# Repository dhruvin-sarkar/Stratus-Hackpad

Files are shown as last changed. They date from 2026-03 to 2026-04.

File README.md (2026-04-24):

# Stratus Hackpad

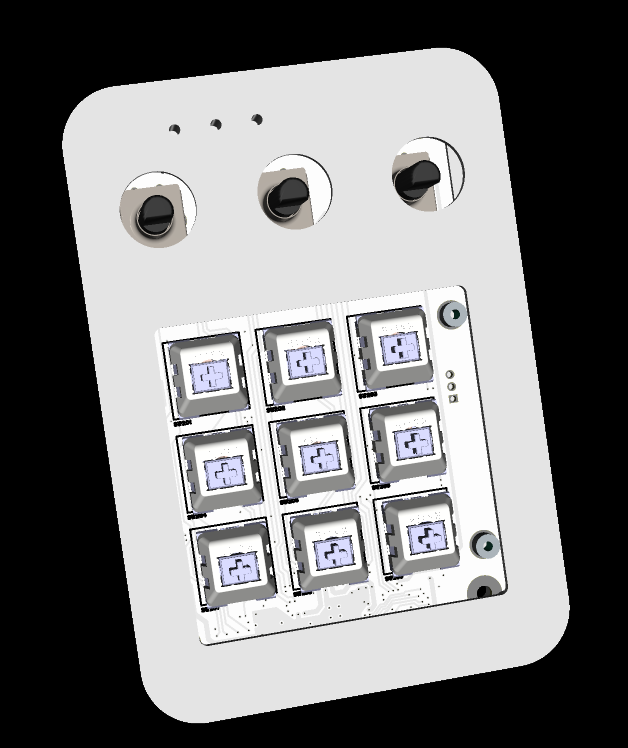
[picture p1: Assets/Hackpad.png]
Stratus Hackpad


---

## Overview

The **Stratus Hackpad** is a DIY macropad. It features nine hot-swap mechanical key switches in a 3×3 layout, three rotary encoders with push-click switches, per-key addressable RGB LEDs viewable through transparent light guides, and a USB-C connection  all controlled by the Raspberry Pi RP2040 microcontroller.

---

## Tutorial Playlist

A full step-by-step video tutorial series covering everything from sourcing parts to flashing firmware is coming soon. Follow along to build your own Stratus Hackpad from scratch!

> **[Tutorial Playlist — Coming Soon]**

The playlist will cover PCB ordering, soldering the SMD components, assembling the case, flashing QMK/KMK firmware, and customising your layout.

---

## Photos

| Assembled | Inside | PCB |
|---|---|---|
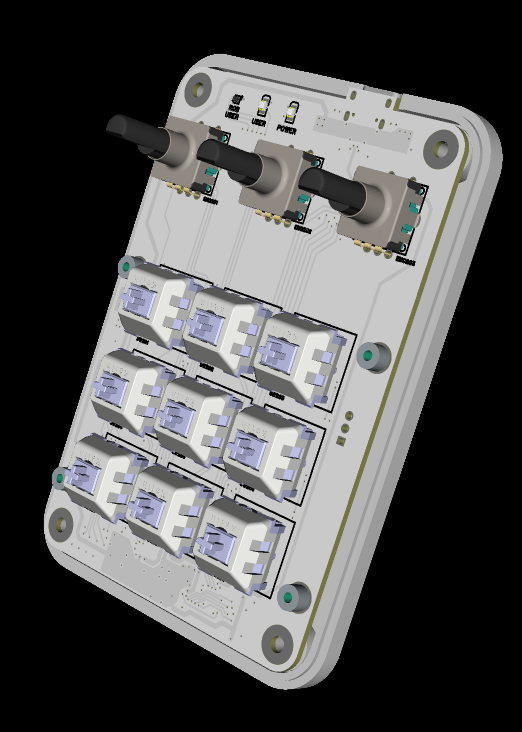
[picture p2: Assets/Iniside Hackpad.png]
Inside
| Hackpad |  | PCB |

| Case Showcase | Schematic — MCU Page | Schematic — Other |
|---|---|---|
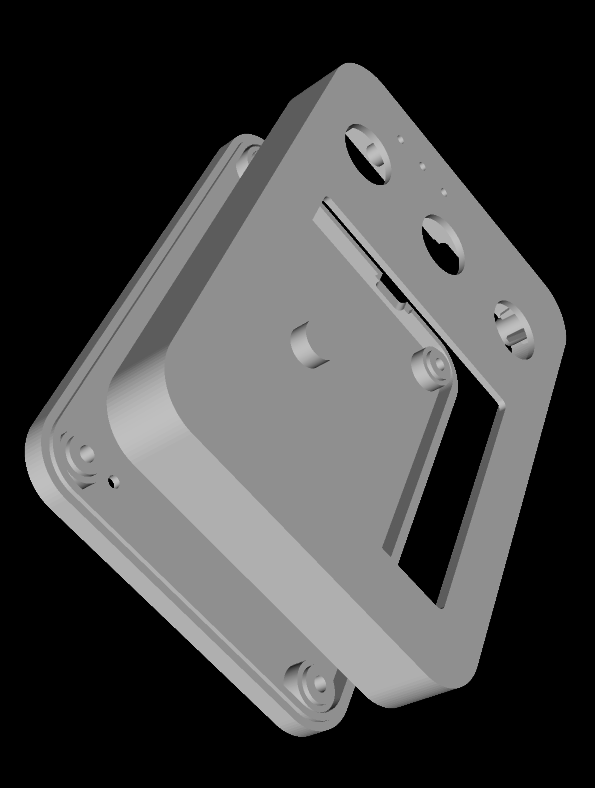
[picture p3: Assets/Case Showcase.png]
Case
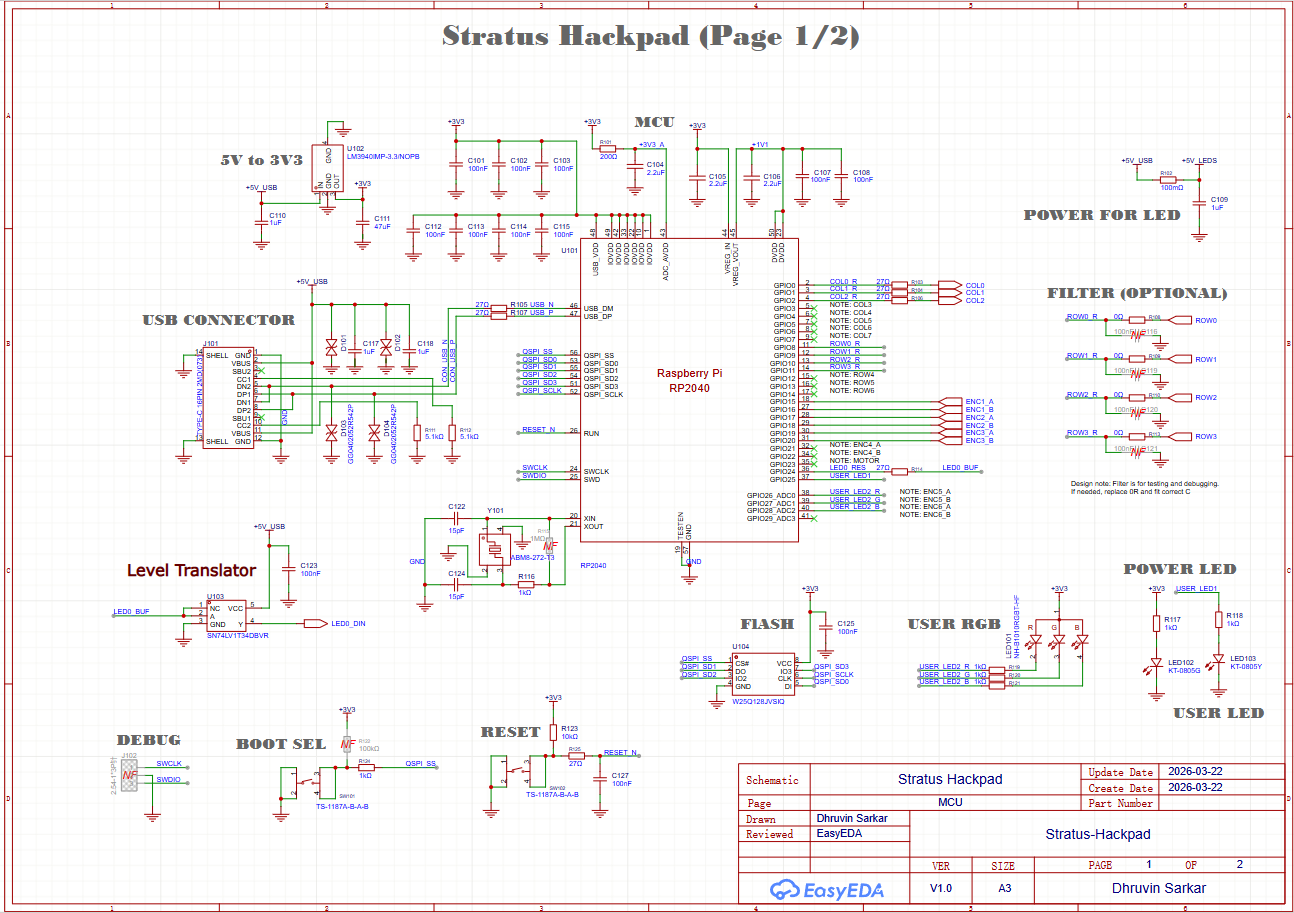
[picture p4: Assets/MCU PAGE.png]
MCU Page
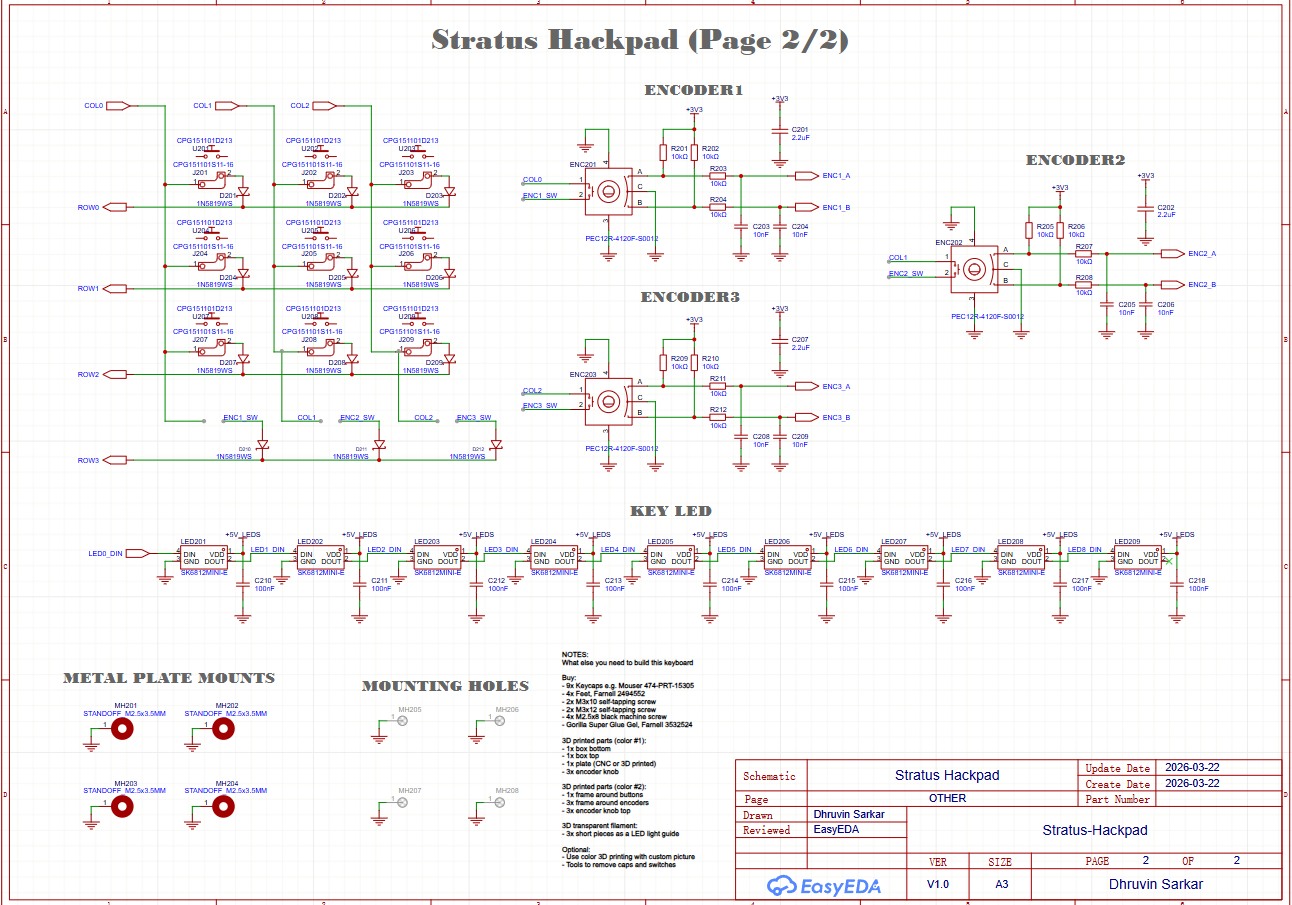
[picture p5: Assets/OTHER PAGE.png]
Other Page
|  |  |  |

---

## Bill of Materials (PCB)

All PCB components are sourced primarily from **LCSC**, with standoffs from **Farnell**.

| # | Qty | Component | Designator | Part Number | Supplier |
|---|-----|---|---|---|---|
| 1 | 7 | Cap 2.2µF 0402 | C101, C105–C107, C201, C202, C207 | CL05A225MQ5NSNC | LCSC C12530 |
| 2 | 21 | Cap 100nF 0402 | C102–C104, C108–C109, C113–C116, C125–C127, C210–C218 | CL05B104KO5NNNC | LCSC C1525 |
| 3 | 4 | Cap 1µF 0402 | C110, C111, C118, C119 | CL05A105KA5NQNC | LCSC C52923 |
| 4 | 1 | Cap 47µF 1206 | C112 | CL31A476MPHNNNE | LCSC C96123 |
| 5 | 2 | Cap 15pF 0402 | C123, C124 | CL05C150JB5NNNC | LCSC C86285 |
| 6 | 6 | Cap 10nF 0402 | C203–C206, C208, C209 | CL05B103KB5NNNC | LCSC C15195 |
| 7 | 4 | TVS Diode (bi-dir) | D101–D104 | GG0402052R542P | LCSC C1973257 |
| 8 | 12 | Schottky Diode 1N5819WS | D201–D212 | 1N5819WS | LCSC C191023 |
| 9 | 3 | Rotary Encoder PEC12R | ENC201–ENC203 | PEC12R-4120F-S0012 | LCSC C143801 |
| 10 | 1 | USB-C Connector 16-pin | J101 | TYPE-C 16PIN 2MD(073) | LCSC C2765186 |
| 11 | 9 | Kailh Hot-swap Socket | J201–J209 | CPG151101S11-16 | LCSC C5156480 |
| 12 | 1 | RGB LED Array (status) | LED101 | NH-B1010RGBT-HF | LCSC C2874113 |
| 13 | 1 | LED Green 0805 | LED102 | KT-0805G | LCSC C2297 |
| 14 | 1 | LED Yellow 0805 | LED103 | KT-0805Y | LCSC C2296 |
| 15 | 9 | SK6812MINI-E RGB LED | LED201–LED209 | SK6812MINI-E | LCSC C5149201 |
| 16 | 4 | Standoff M2.5×3.5mm | MH201–MH204 | 3757968 | Farnell |
| 17 | 1 | Resistor 200Ω 0402 | R101 | 0402WGF2000TCE | LCSC C25087 |
| 18 | 1 | Resistor 100mΩ 1206 | R102 | 1206W4F100LT5E | LCSC C25334 |
| 19 | 7 | Resistor 1kΩ 0402 | R103–R107, R121, R124 | 0402WGF1001TCE | LCSC C11702 |
| 20 | 7 | Resistor 27Ω 0402 | R108–R112, R117, R125 | 0402WGF270JTCE | LCSC C25100 |
| 21 | 4 | Resistor 0Ω 0402 | R113–R116 | 0402WGF0000TCE | LCSC C17168 |
| 22 | 2 | Resistor 5.1kΩ 0402 | R118, R119 | 0402WGF5101TCE | LCSC C25905 |
| 23 | 13 | Resistor 10kΩ 0402 | R123, R201–R212 | 0402WGF1002TCE | LCSC C25744 |
| 24 | 2 | Tactile Switch 5.1mm | SW101, SW102 | TS-1187A-B-A-B | LCSC C318884 |
| 25 | 9 | Kailh Switch CPG151101S21 | SW201–SW209 | CPG151101S21 | LCSC C404351 |
| 26 | 1 | RP2040 MCU | U101 | RP2040 | LCSC C2040 |
| 27 | 1 | LDO Regulator 3.3V | U102 | LM3940IMP-3.3/NOPB | LCSC C140319 |
| 28 | 1 | Buffer SN74LV1T34 | U103 | SN74LV1T34DBVR | LCSC C100024 |
| 29 | 1 | Flash 128Mbit SPI | U104 | W25Q128JVSIQ | LCSC C97521 |
| 30 | 1 | Crystal 12MHz | Y101 | ABM8-272-T3 | LCSC C20625731 |

---

### Hardware to Buy

- **9× Keycaps** — e.g. Mouser `474-PRT-15305`
- **4× Rubber feet** — Farnell `2494552`
- **2× M3×10 self-tapping screws**
- **2× M3×12 self-tapping screws**
- **4× M2.5×8 black machine screws**
- **Gorilla Super Glue Gel** — Farnell `3532524`

### 3D Printed Parts — Colour #1 (main body colour)

- 1× Box bottom
- 1× Box top
- 1× Switch plate (can also be CNC machined)
- 3× Encoder knob (body)

### 3D Printed Parts — Colour #2 (accent colour)

- 1× Frame around buttons
- 3× Frame around encoders
- 3× Encoder knob top

### 3D Printed — Transparent Filament

- 3× Short pieces used as LED light guides (one per encoder/LED position)
---

## Firmware

The Stratus Hackpad is compatible with both **QMK** and **KMK** (CircuitPython-based). Starter configuration files are provided.

---

## Contributing

Pull requests and issues are welcome! If you build one, share a photo it's always great to see the community's builds.

# Set shortcuts
To set shortcuts on your keyboard, use VIA.
1. When connecting your keyboard for very first time, go to https://usevia.app/design click LOAD and use keyboard_layout_for _VIA.json to see your keyboard in VIA
1. To change shortcuts, go to https://usevia.app/ and in the right top corner click on "Authorize New +"
1. Pair your Stratus Hackpad
1. Set shortcuts

# Steps to update firmware
1. Connect your keyboard to PC
1. Double tap the reset button on your keyboard
1. Keyboard will show up as an USB storage
1. Copy and paste uf2 firmware file from your PC directly to the USB storage main directory

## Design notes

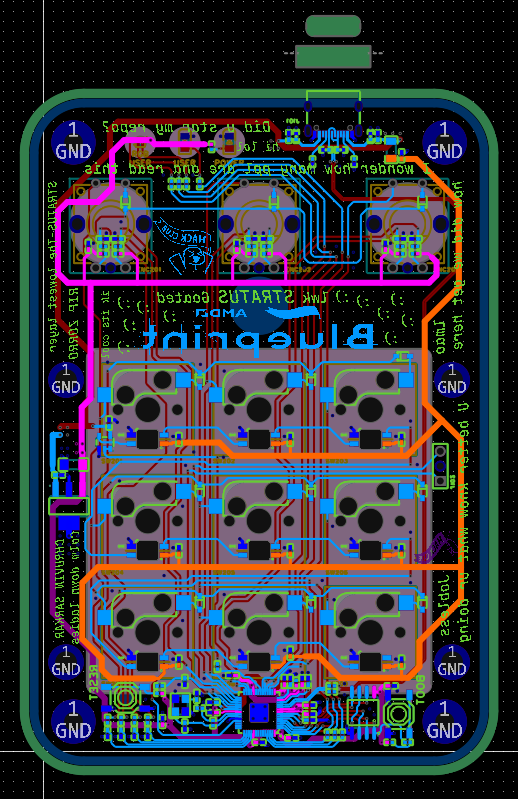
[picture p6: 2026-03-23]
Assets/PCB Vert.png

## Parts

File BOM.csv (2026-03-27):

Name | Purpose | Quantity | Total Cost | Link | Distributor
100nF Capacitor (CL05B104KO5NNNC) | Decoupling capacitor for MCU and LED power pins | 21 | $1.05 | https://www.lcsc.com/product-detail/C1525.html | LCSC
2.2uF Capacitor (CL05A225MQ5NSNC) | Bulk decoupling and power filtering | 6 | $0.6 | https://www.lcsc.com/product-detail/C12530.html | LCSC
1uF Capacitor (CL05A105KA5NQNC) | Power filtering for regulator and USB | 4 | $0.6 | https://www.lcsc.com/product-detail/C52923.html | LCSC
47uF Capacitor (CL31A476MPHNNNE) | Bulk output capacitor for LDO regulator | 1 | $0.25 | https://www.lcsc.com/product-detail/C96123.html | LCSC
15pF Capacitor (CL05C150JB5NNNC) | Crystal oscillator load capacitors | 2 | $0.2 | https://www.lcsc.com/product-detail/C86285.html | LCSC
10nF Capacitor (CL05B103KB5NNNC) | Low pass filter capacitors for encoder signals | 6 | $0.3 | https://www.lcsc.com/product-detail/C15195.html | LCSC
ESD Protection Diode (GG0402052R542P) | USB-C ESD protection | 4 | $9.36 | https://www.lcsc.com/product-detail/C1973257.html | LCSC
Schottky Diode 1N5819WS | Keyboard matrix anti-ghosting diodes | 12 | $3.48 | https://www.lcsc.com/product-detail/C191023.html | LCSC
Rotary Encoder PEC12R-4120F-S0012 | Rotary encoders with push switch | 3 | $9.3 | https://www.lcsc.com/product-detail/C143801.html | LCSC
USB-C Connector TYPE-C 16PIN 2MD(073) | USB-C connector for power and data | 1 | $0.67 | https://www.lcsc.com/product-detail/C2765186.html | LCSC
Kailh Hotswap Socket CPG151101S11-16 | Hotswap sockets for mechanical switches | 9 | $5.94 | https://www.lcsc.com/product-detail/C5156480.html | LCSC
RGB LED NH-B1010RGBT-HF | User RGB status indicator LED | 1 | $0.5 | https://www.lcsc.com/product-detail/C2874113.html | LCSC
Green LED KT-0805G | User programmable indicator LED | 1 | $0.8 | https://www.lcsc.com/product-detail/C2297.html | LCSC
Yellow LED KT-0805Y | Power indicator LED | 1 | $0.33 | https://www.lcsc.com/product-detail/C2296.html | LCSC
SK6812MINI-E RGB LED | Per-key RGB LEDs for keyboard backlight | 9 | $4.5 | https://www.lcsc.com/product-detail/C5149201.html | LCSC
M2.5x3.5mm Standoff | Metal plate standoffs for switch plate support | 4 |  | https://www.farnell.com/search/?st=9774035151 | FARNELL
200Ω Resistor (0402WGF2000TCE) | Current limiting resistor for power LED | 1 | $0.05 | https://www.lcsc.com/product-detail/C25087.html | LCSC
100mΩ Resistor (1206W4F100LT5E) | Current sense resistor for LED power | 1 | $0.04 | https://www.lcsc.com/product-detail/C25334.html | LCSC
27Ω Resistor (0402WGF270JTCE) | USB data line and signal series termination resistors | 7 | $0.35 | https://www.lcsc.com/product-detail/C25100.html | LCSC
0Ω Resistor (0402WGF0000TCE) | DNF filter jumpers | 4 | $0.2 | https://www.lcsc.com/product-detail/C17168.html | LCSC
5.1kΩ Resistor (0402WGF5101TCE) | USB-C CC pull down resistors | 2 | $0.1 | https://www.lcsc.com/product-detail/C25905.html | LCSC
1kΩ Resistor (0402WGF1001TCE) | LED current limiting and signal resistors | 7 | $0.35 | https://www.lcsc.com/product-detail/C11702.html | LCSC
10kΩ Resistor (0402WGF1002TCE) | Pull-up resistors for encoders and reset | 13 | $0.65 | https://www.lcsc.com/product-detail/C25744.html | LCSC
Tactile Switch TS-1187A-B-A-B | Boot and reset buttons | 2 | $1.1 | https://www.lcsc.com/product-detail/C318884.html | LCSC
RP2040 Microcontroller | Main MCU for keyboard firmware | 1 | $3.46 | https://www.lcsc.com/product-detail/C2040.html | LCSC
LM3940IMP-3.3 LDO Regulator | 5V to 3.3V voltage regulator | 1 | $1.55 | https://www.lcsc.com/product-detail/C140319.html | LCSC
SN74LV1T34DBVR Level Translator | 3.3V to 5V logic level buffer for RGB LEDs | 1 | $0.51 | https://www.lcsc.com/product-detail/C100024.html | LCSC
W25Q128JVSIQ Flash Memory | 16MB external flash for firmware storage | 1 | $0.34 | https://www.lcsc.com/product-detail/C97521.html | LCSC
Kailh Key Socket CPG151101D213 | Through-hole hotswap sockets | 9 | $13.32 | https://www.lcsc.com/product-detail/C400235.html | LCSC
12MHz Crystal ABM8-272-T3 | Crystal oscillator for RP2040 USB clock | 1 | $1.84 | https://www.lcsc.com/product-detail/C20625731.html | LCSC

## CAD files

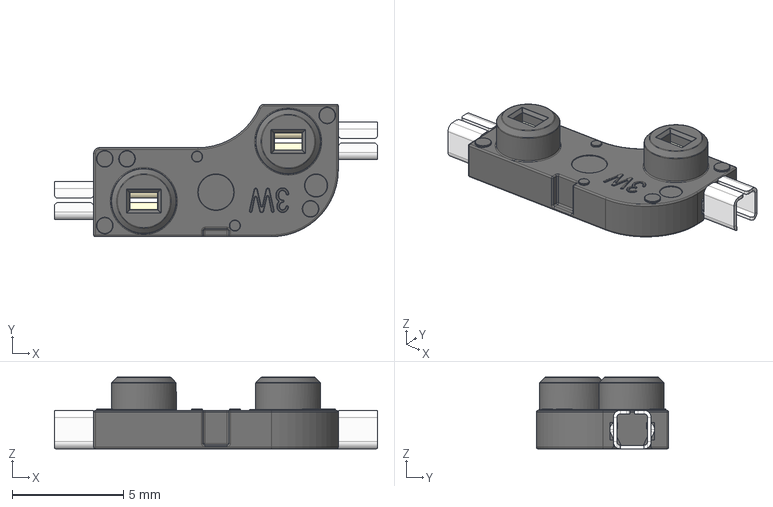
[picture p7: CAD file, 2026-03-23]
3D models/Kailh Hotswap MX v22 DS v1_0.step
14.5 x 5.95 x 3.22 mm

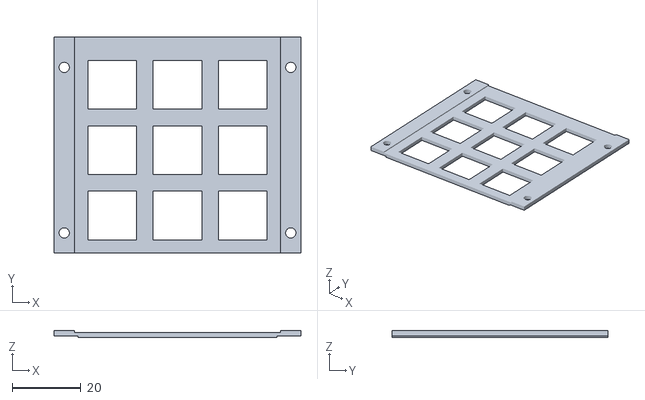
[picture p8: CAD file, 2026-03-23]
Manufacturing/Knobs and Plates/plate_for_industrial_printing_2mm.stl
72.0 x 63.0 x 2.00

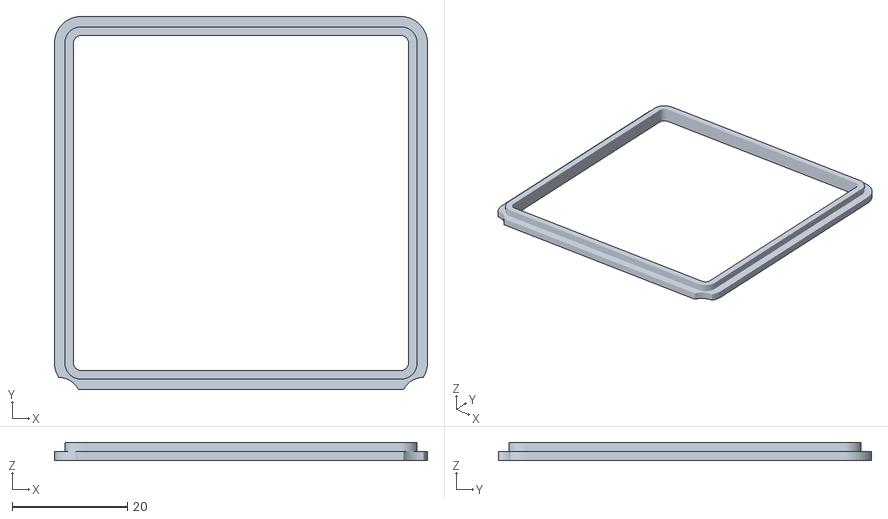
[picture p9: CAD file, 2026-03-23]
Manufacturing/More 3D components/frame.stl
64.8 x 64.8 x 3.20

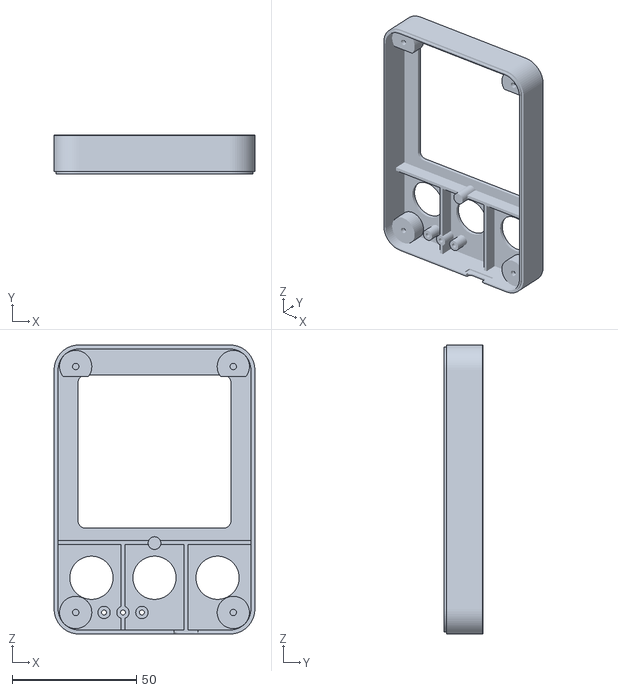
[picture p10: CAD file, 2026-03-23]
Manufacturing/Top and Bottom Case/case-top.obj
80.9 x 15.7 x 116.4

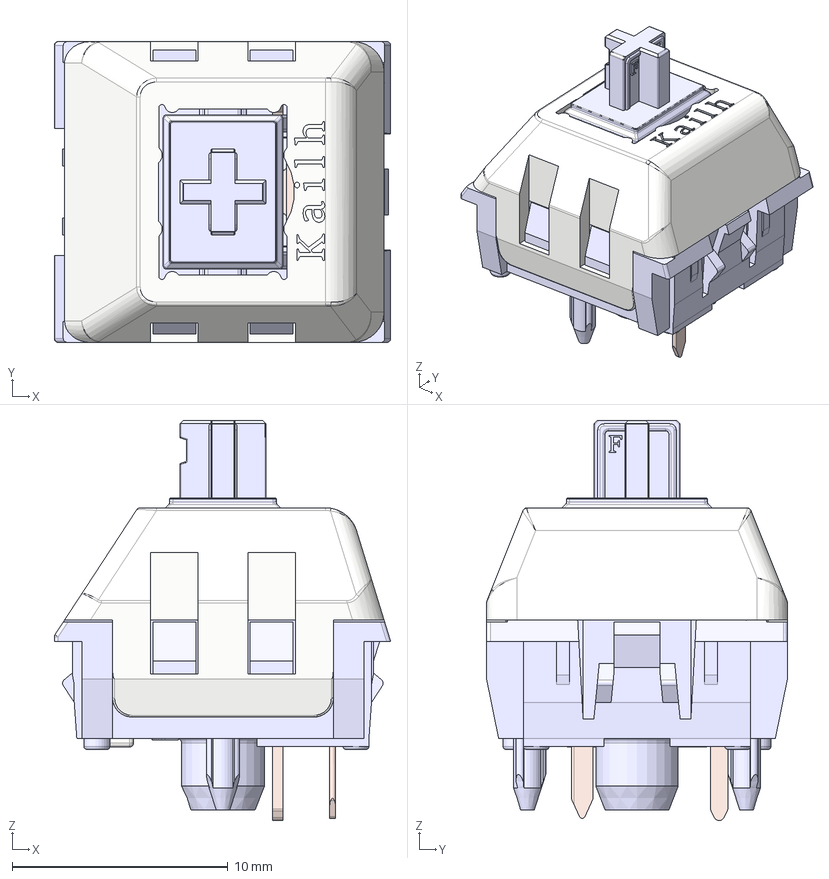
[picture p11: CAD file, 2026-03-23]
3D models/Kailh Polia DS v1_0.step
15.6 x 14.0 x 18.5 mm
Housing
ThickContact
SpringContact
Stem
Lid

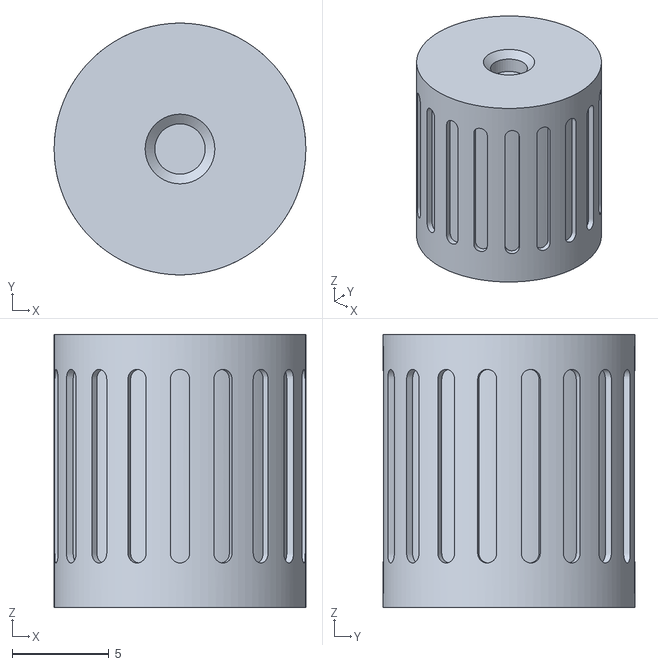
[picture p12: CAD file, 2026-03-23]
Manufacturing/Knobs and Plates/knob_body_print_3x.stl
13.0 x 13.0 x 14.1

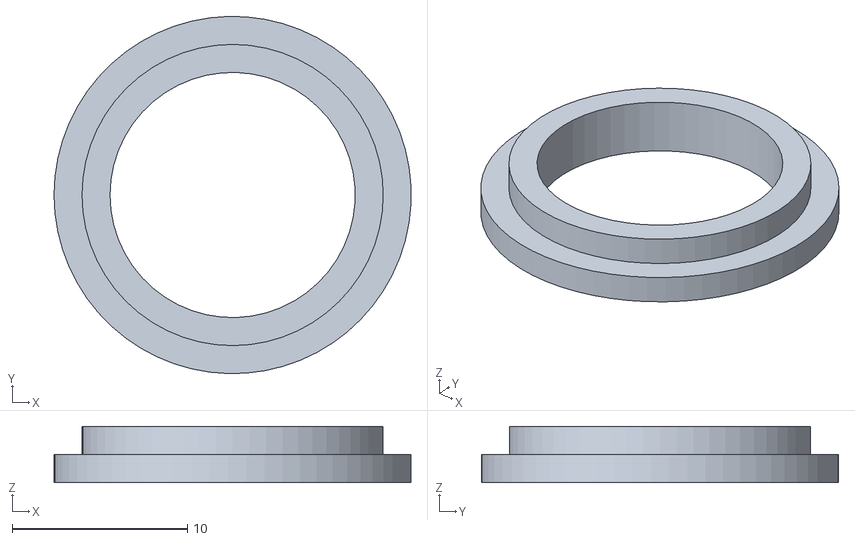
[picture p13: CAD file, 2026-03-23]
Manufacturing/More 3D components/ring_print_3x.stl
20.4 x 20.4 x 3.20

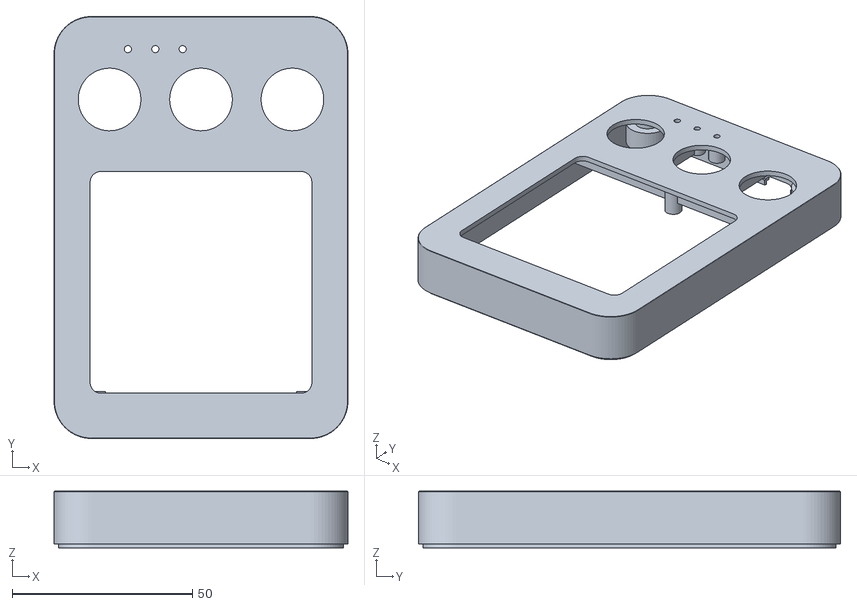
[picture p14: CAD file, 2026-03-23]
Manufacturing/Top and Bottom Case/top.stl
81.7 x 117.2 x 15.7

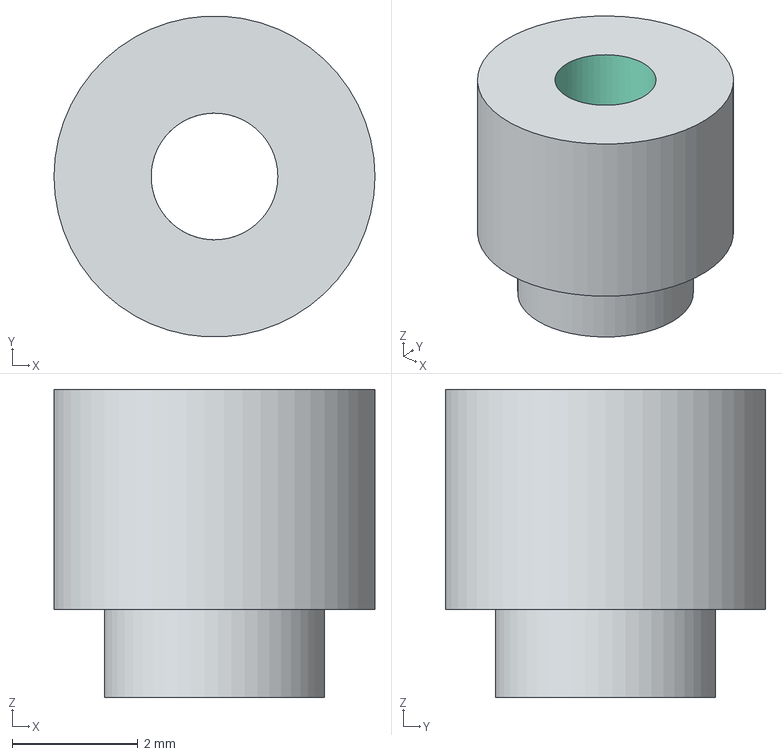
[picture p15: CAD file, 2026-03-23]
3D models/STP_9774035151_rev1 DS v1_0.stp
5.10 x 5.09 x 4.90 mm

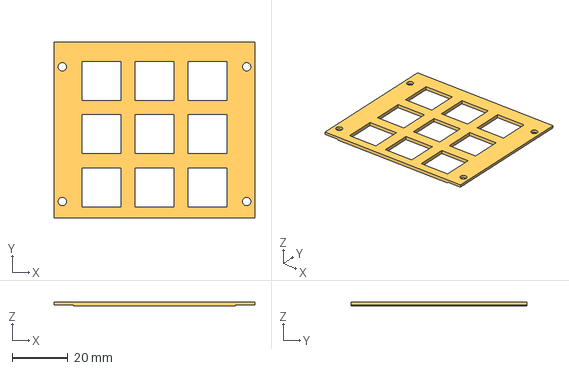
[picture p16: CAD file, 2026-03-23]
Manufacturing/Knobs and Plates/plate_for_cnc.step
72.0 x 63.0 x 1.50 mm

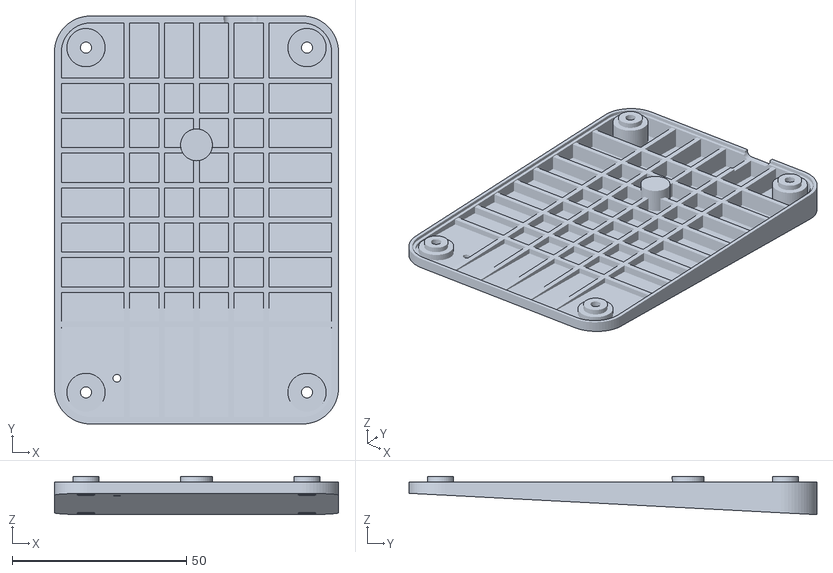
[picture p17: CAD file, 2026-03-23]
Manufacturing/Top and Bottom Case/bottom.stl
81.7 x 117.2 x 11.0

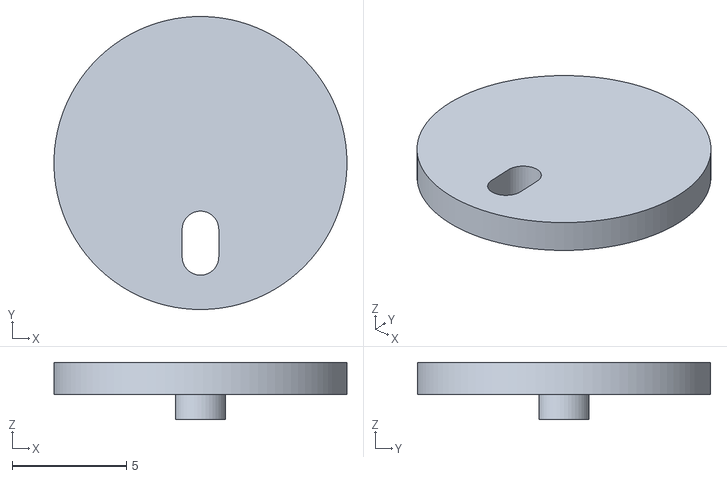
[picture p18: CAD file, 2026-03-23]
Manufacturing/Knobs and Plates/knob_top_print_3x.stl
12.8 x 12.8 x 2.50

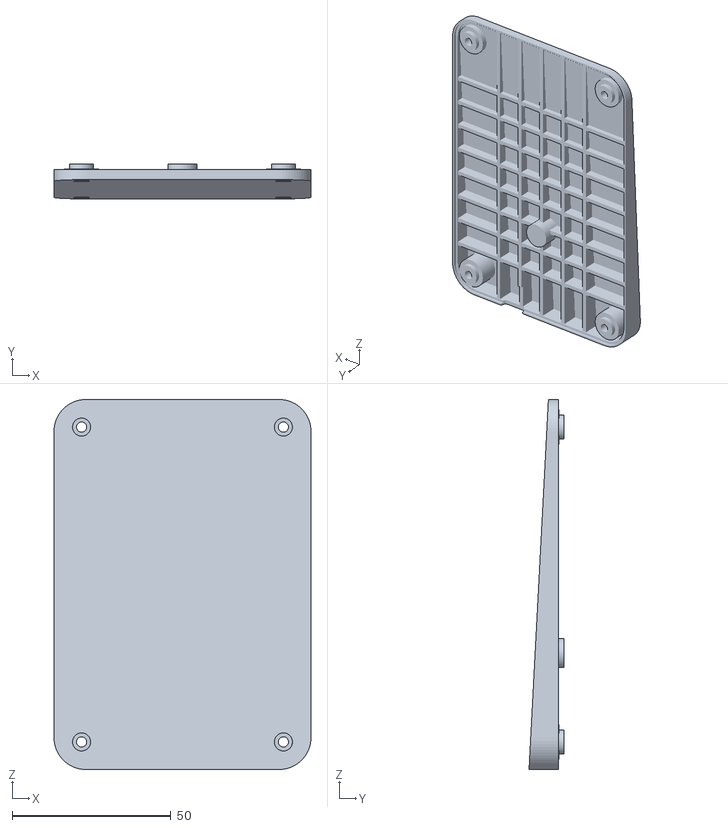
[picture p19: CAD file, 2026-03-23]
Manufacturing/Top and Bottom Case/case-bottom.obj
80.9 x 11.0 x 116.4

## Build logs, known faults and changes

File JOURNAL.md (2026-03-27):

<!--
  This journal is auto generated by Stasis.
-->

# 3/27/2026 10 AM - CASEE!!!

_Time spent: 1.25h_

After all that PCB work this is what the render looks like it looks peak but i still have to work on the case which is wat im gna do 



First I created the base enclosure shape with the correct X Y position, width, height and rounded corners
Then I added the top shell layer with the right depth values to form the actual box



I drew a rectangle cutout above the switch area to create the opening for the keys
Then I added circular cutouts above each of the three encoders and rounded the corners so it looked cleaner







I created three columns in the enclosure above each LED to hold transparent filament which guides the light up to the top of the box
Then I added holes through the top of those columns so the light actually shines through



I drew a rectangle cutout on the side of the enclosure for the USB connector and adjusted the position until it lined up correctly
Then I added a second smaller cutout for the PCB edge itself since it was colliding with the enclosure wall









I added screw pillars to the top enclosure above each mounting hole with stiffeners so they dont snap when screwed
 I did the same for the bottom enclosure
 I drew a circular support on the bottom enclosure right below the encoder area to stop the PCB from bending when u know u press the keys












# 3/27/2026 10 AM - Super Cool HackClub PCB

_Time spent: 0.4166666666666667h_

First I enabled reference designators for the key switches and encoders and repositioned them so they lined up cleanly
Then I added silkscreen labels for the LEDs, boot and reset buttons, board name, version, copyright







This part was super cool cuz i added a bunch of puns and like stuff a lot of ppl wont see like references symmbols text all over the place etc 

I added a Hackclub logo using a gold finish where the Hackclub logo is placed on the mask layer over a copper area so it comes out gold

also a text honouring my dog zorro that passed during the time I was working on this RIP





# 3/27/2026 9 AM - Improving PCB Design

_Time spent: 0.75h_

First I changed the copper region connection to direct Then I added extra vias throughout the power areas cuz a single via has limited current capacity so more vias means better power delivery



This overall Improved the +5V_USB



I placed a bunch of vias around the voltage regulator and drew ground and 3V3 polygons around them since its a linear regulator and gets hot, the inner ground planes help spread the heat





 I went through and moved tracks further apart where there was space to reduce crosstalk well this was mostly js to make it look better but still its a good thing to do 







 I updated the thermal relief width to 15mil on the inner ground planes to make through hole soldering easier

I placed ground vias next to all the spots where tracks change between top and bottom layer, these connect the two inner ground planes together and help control return current paths





The output of all this looked super clean or well cleaner














# 3/27/2026 9 AM - Even More PCB design

_Time spent: 1.75h_

First I routed the debug signal pins up from the MCU area placing a via to change layers Then I connected both pins on the bottom layer keeping the tracks clean and away from holes



 After that I double checked the spacing between the tracks and from the holes cuz this area had some tight spots



 connected the 5.1K resistors for the USB configuration pins Then I routed the filter connections and the power LED tracks in the remaining free space around that area





I connected all the ground pins around the USB connector, there were a lot of them
Then I did the same on the other side using X and Y on the keyboard to flip and mirror which was super useful



After that I connected the power track to the ESD protection diode and then to the capacitor placing a via for the layer change
Then I connected the 0.1 ohm resistor for the LED power supply and placed a via for that too



After that I connected all the remaining ground pins using 20mil tracks and copy pasted where I could 

I used a wider 30mil then 40mil track for the 5V LED power since its carrying more current
when connecting power for Key LEDs



Then I routed it down the board to the first LED making sure to stay away from the hotswap socket holes



After that I connected the rest of the LEDs in the chain drawing the power track around the buttons to reach each one



I started the 3.3V connection I connected all three encoders to 3.3V since they all need it, routing up to each one
Then I connected the pull up resistors on each encoder



After that I connected all the remaining components around the MCU that needed 3.3V, running the track on the top layer and using vias to get down to each component



I ran the DRC check to see what was still missing
Then I connected the two nets that were flagged as unconnected that I had missed



Then I connected the two nets that were flagged as unconnected that I had missed
I connected the missing 1.1V power pin on the top layer, space was tight but i managed lmfao
After that I connected the remaining LED pads that were flagged

and fixed the remaning issues they're were quite a few but it didnt take thaaat long 

















# 3/26/2026 5 PM - Updating the Logic Level Buffer

_Time spent: 0.3333333333333333h_

I realised the original buffer chip was kinda cooked for this design it needed up to 3.33V input to register HIGH which is right at the MCUs supply voltage and way too unreliable



 I found a better TI buffer specifically made for 3.3V to 5V level translation with a much lower input threshold, around 2V for HIGH and 0.8V for LOW






# 3/26/2026 5 PM - More PCB design

_Time spent: 2.25h_

First I connected the boot button ground with a short track to a via 



 I completed the remaining MCU pin fanouts routing signals out to vias  I made sure to keep as much space between tracks as possible around the MCU cuz its the most dense part of the board
I double checked all via and track distances from the board edge to avoid any manufacturing issues



I routed Column 0 vertically up the board on the top layer hitting each button switch then continuing up to the encoder switch since it shares the same column net After that I repeated the same for Column 1 and Column 2I made sure to keep clearance from the hotswap socket drill holes throughout cuz tracks too close to holes can get rejected in manufacturing





I routed the row lines from the filter components near the MCU upward connecting all the diodes in each row
Then I connected each switch diode on the bottom layer with short horizontal tracks keeping to the routing convention





 I routed encoder A and B signal pins out to vias then continued to the MCU on the other layer
Then I drew the full routing for one encoder first and just copied and pasted the whole layout to the other two  I connected the pull up resistors and decoupling caps with short local tracks for each encoder





 routed the user power LED from the MCU GPIO through a resistor to the LED pad on the top layer
Then I routed the RGB SK6812 data chain so output of LED 1 feeds into input of LED 2 daisy chained
After that I copy pasted the ground and power via connections across all LEDs





First I looked up the impedance requirements USB needs 90 ohms differential and standard digital signals need 50 ohms Then I used JLCPCBs stackup calculator and calculated that 6.1mil track width with 7.5mil spacing hits 90 ohms 





I placed the via pairs I used differential pair routing mode to route D+ and D- After that I routed from the USB connector through the ESD resistors down toward the MCU

















# 3/26/2026 4 PM - PCB Design

_Time spent: 1.5h_

First of I set via imensions to 24mil outer diameter and 12mil drill size I made sure to check the JLCPCBS manufacturing clearences to confirm if its fine

then I set the default track width to 8mil and clearance to 7mil calculating the space between MCU pads it was like 7.9mil so i chose the 8 mil track/7mil spacing to fit tracks between the pads 

I set special clearance rules for line to slot, line to hole and board outline since these need more margin that standard track to track spacing 



Then I routed the bottom MCU pins using 8mil tracks on the bottom layer connected decoupling caps, filters, and resistors



Then I used 8.1mil track width for power traces these are slightly wider to differentiate power nets from signal nets and for filtering purposes later







Then I connected crystal oscillator pins kepping the clock signal isolated from other signals to avoid crosstalk
then i placed dedicated vias for every power and ground pin 
I used 20mil track width for power connections (VCC/GND) going into vias to handle current properly





I left USB differential pair pins (D+ / D-) unrouted rn since they needed special differential pair routing rules
Routed around the flash memory pins keeping the SPI clock signal away from other tracks



Then I worked on the flash memory chip I routed flash SPI signals (CLK, MOSI, MISO, CS) from MCU to the flash chip using 8mil tracks



















# 3/26/2026 7 AM - PCB Design and component placement

_Time spent: 2.416666666666667h_

I added the RP2040 microcontroller on the bottom layer to keep assembly cheaper. Its super important to align pin number one in the bottom right corner for correct orientation



Then I moved on to the RBG LEDs for status indicators in the top layer I made it so that the rotation of these LEDs line up their ground pins the top left corner which makes the layout process





Then I added the debug header and its position is chosen to make wiring easier.
 


Now placing the Decoupling Capacitors these capacitors are placed as close to the microcontroller power pins as possible to make sure stable power delivery and I made sure to leave enough space for tracks to run underneath





Then came the USB Resistors & Crystal Circuit
these resistors for the usb dat lines are places near the MCU the crystal oscillator and its capacitors are placed close to make sure a proper clock signal



after that I placed the series termination and filters 
series resistors are placed near the MCU to manage the signal reliability and then the filters are arranged js in free space



and then the flash memory chip is placed with its decoupling capacitor 



Then the Reset and Boot buttons


  


After that came ESD protection components for the usb c protection and power stuff its placed close to the connector pins to protect the circuit 



Then I added the voltage regulator and level translator 



The diodes and Encoder Components are placed next the diodes are placed in the matrix for rotary encoders all resistors and capacitors are placed 





Then finishing it off I added the decoupling capacitors for LEDs and then I also removed the 3D model for the debuh header cuz it might cause issues in manufacturing 



And the final output after this looked amazing 





















# 3/25/2026 8 PM - PCB Setup and Board Outline

_Time spent: 1.5h_

First I changed the grid to 100mils for better placements of components 
the first thing i needed to do was place the mounting holes to make sure the PCB would fit correctly in the future case 



Then came placing the usb-c connector on the bottom layer of the PCB I manually drew a custom board outline to make sure the connecter was properly positioned at the edge of the board cuz i kept messing up with a simple outline



then i placed the input components the rotary encoders were placed in their positions and then the buttons for the keyboard at 19.05mm as standard spacing between the keys



then i placed the hotswap sockets at the bottom layer
at which point I could def see the keyboard taking shape




With the rotary encoders and the 3D model for the switches imported this is really starting to look more and more like an actual keyboard



After this I added the LEDs for the classic gamer RGB



then I worked on the metal plate holders for supporting the switch structure












# 3/25/2026 7 PM - Initial PCB import and 3D render

_Time spent: 0.5h_

After I finished the last bits of the Other page and the keyboard matrix 
I checked DRC and fixed any connection issues and any other problems that occured which werent many
Since we are done with both schematic pages I can finally import the project to a pcb 



this was the initial stages and well as you expect this it what it would look like since its js all the components laid out 

The 3D render didnt look much better or closer to the final product either but this was huge progress 






# 3/25/2026 7 PM - Im stupid and I forgot the Crystal circuit

_Time spent: 0.3333333333333333h_

Im acctually a little stupid and I overlooked one of the most important and crucial components the crystal circuit for the RP2040

It provides the timing signals needed for the RP2040 to communicate with the USB connecter and flash memory etc. its a super imp component that I mustve thought I completed when I was designing the intial MCU page which in all honesty I should have done



Reference from the RP2040 datasheet






# 3/25/2026 7 PM - Connecting the Keyboard Matrix and Mapping

_Time spent: 3.75h_

The keyboard matrix connection process involves organizing switches and encoders into a matrix to minimize the number of microcontroller pins required. 
I settled on 9 keys and 3 knobs I mean what more could you need its balanced aswell as providing a lot of funcionality.

I added three rotary encoders creating a custom library symbol to clearly show the internal switch and rotating contacts 



 



Each mechanical switch is paired with a diode connecting in as specific direction to prevent ghosting which is super imp for accurate key presses



I used net labels to connect these matrix lines to the microcontroller which then handles the logic of detecting which key is pressed.

I also mapped the rows and coloums in the info.json 



To ensure stable signal I added series termination resistors to the column lines 

and Low pass filters are included for noise reduction tho they arent fitted initially 



encoder switches are also connected to the matrix in the 3rd row



I added SK6812MINI-E RGB LEDs for layer indication
creating a custom symbol to clarify the voltage and data connections and well also RGB 



Because the LEDs require 5V but the microcontroller operates at 3.3V I added a logic buffer to reliably translate the signal levels



Iadded mounting holes for PCB fastening and specialized standoffs to secure the metal switch plate to the PCB



For debugging and programming the RP2040 microcontroller I added a debug header this allows you to connect to a debugger like a pico or j-link to flash firmware



inalizing the connections for the rotary encoders to the microcontroller I mapped the remaining encoders to specific GPIO pins on the RP2040 for functionality
I connected the encoder switches to Row 3 of the keyboard matrix so they can be detected alongside the keys
















# 3/25/2026 6 PM - Desinging the 'keys' in the keyboard

_Time spent: 2.5h_

This was the key matrix and component selection part of the Other schematic page on my project
I designed the foundational schematic for Stratus focusing on the switch matrix, Hot swap capabilities cuz Im a keyboard nerd and I would love to test out diff switches and stuff and obviously electronic protection components 

First of I added a mechanical keyboard shaft for the correct socket which ended up being a Kailh socket to allow for future switch customisation 
then I imported the socket and realised the default symbol was inaccurate and created a custom version symbol in my personal libraries to represent it correctly.





To make sure precise alignment for the 3D printed case later, I adjusted the footprint's origin to the center of the mounting hole based on the manufacturer's datasheet.





after adding the socket I began working on the actual mechanical switch component where I again created a custom symbol and footprint component.





then I added 1N4148 diodes to the schematic ensuring they faced the correct direction to prevent ghosting within the keyboard matrix











# 3/25/2026 5 PM - flash memory,boot/reset buttons, Power and user LED

_Time spent: 2.083333333333333h_

After creating the schematic for the microcontroller portion of the keyboard, focusing on the RP2040 chip 
now ill start with the core peripherals needed for microcontroller to function

Flash memory was first i added the W25Q128JVS chip making sure the data and clock pins were connected properly for te firmware storage 


The user interface buttons I added the boot select and reset buttons including the needed RC circuits to make sure the signal is stable and accidental triggers




Then came the LED indicators i added a user LED on GPIO 25 for custom programming and a power LED to provide visual confirmation that the board is working and receiving power.







# 3/25/2026 4 PM - Project Setup and RP2040 Schematic

_Time spent: 2.5h_

First and foremost was the project setup and config I made a project in EasyEDA pro (I chose this over Kicaid due to the lcsc part placement) 
The first 30 mins were spent in setting up the pages for MCU and Other aswell as grid layouts and Titles

An issue I ran into was the issue with creating a custom RP2040 Symbol making sure everything was correct with reference to the relevant datasheets. I researched the best ESD protection diodes for the usb-c connector

I mapped out the decoupling capacitors for the RP2040 and the voltage regulator circuit the 5V to 3.3V, and the usb-c connector pins 

ive uploaded a before and after of the RP2040 before and after the changes aswell the progress up until this point 

next I will begin working on the flash memory and the boot/reset buttons 



After customisation



5V to 3V3



USB connector








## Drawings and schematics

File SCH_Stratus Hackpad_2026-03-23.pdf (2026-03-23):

# Stratus Hackpad (Page 1/2)

# 5V to 3V3

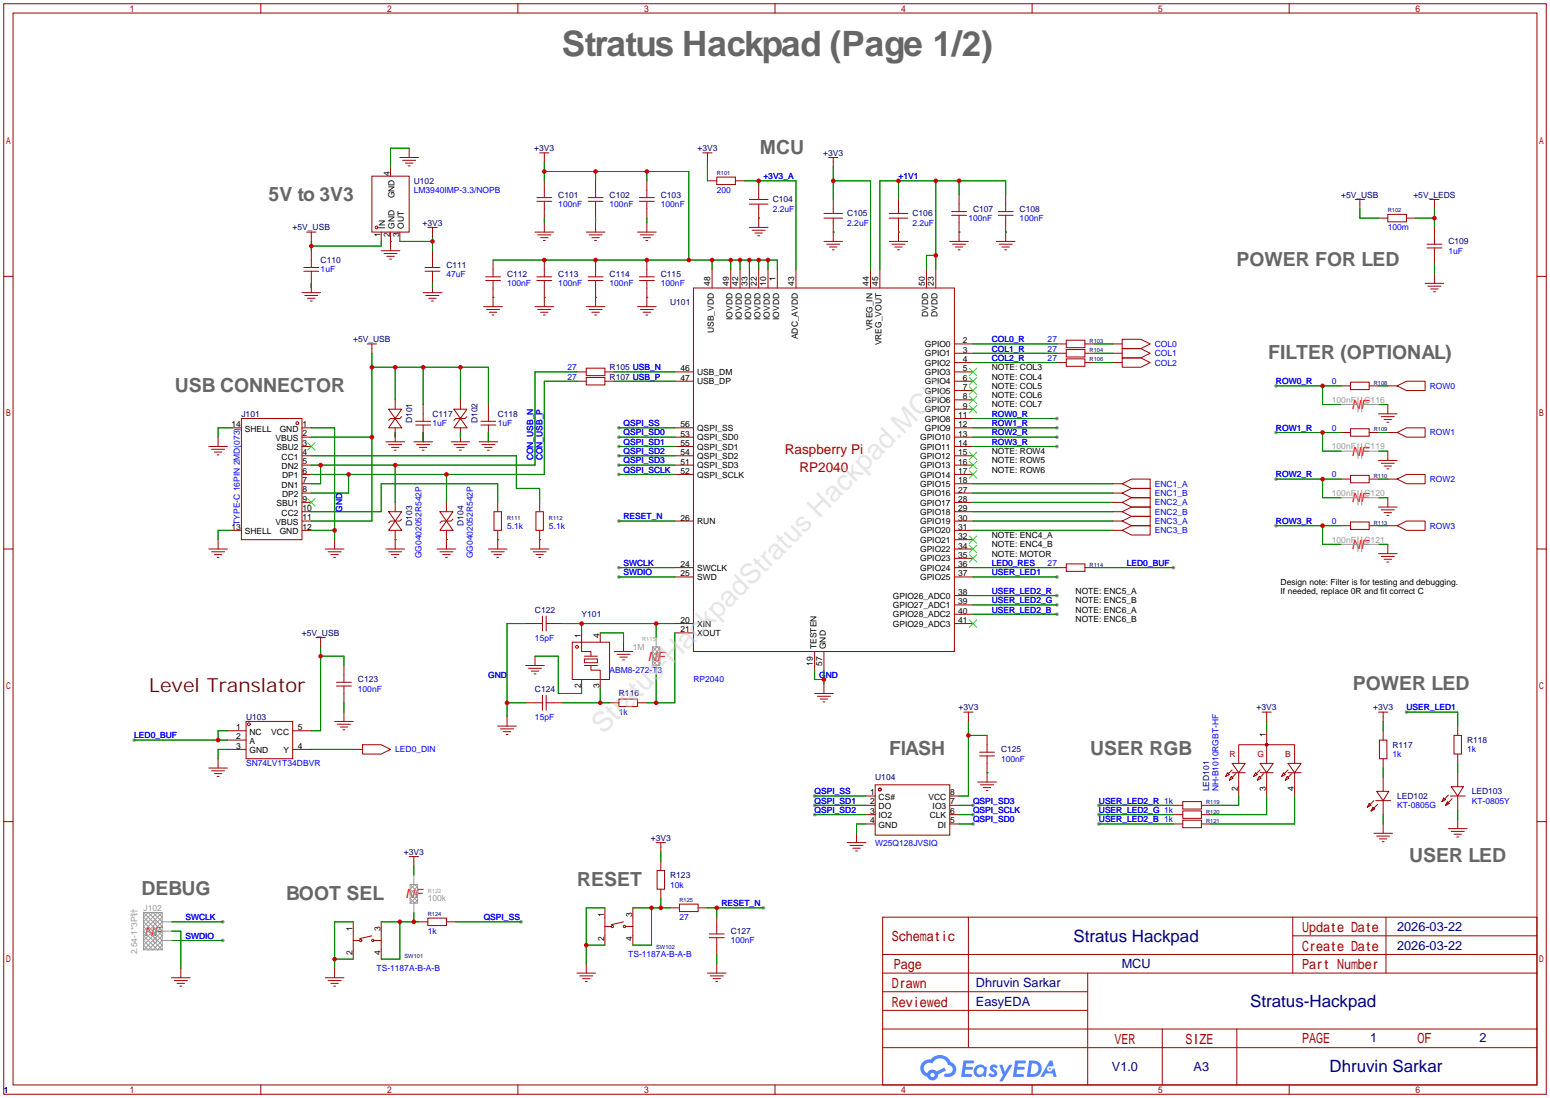
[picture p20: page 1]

Stratus-HackpadStratus Hackpad.MCU

Design note: Filter is for testing and debugging.
If needed, replace 0R and fit correct C

# Stratus Hackpad (Page 2/2)

# ENCODER1

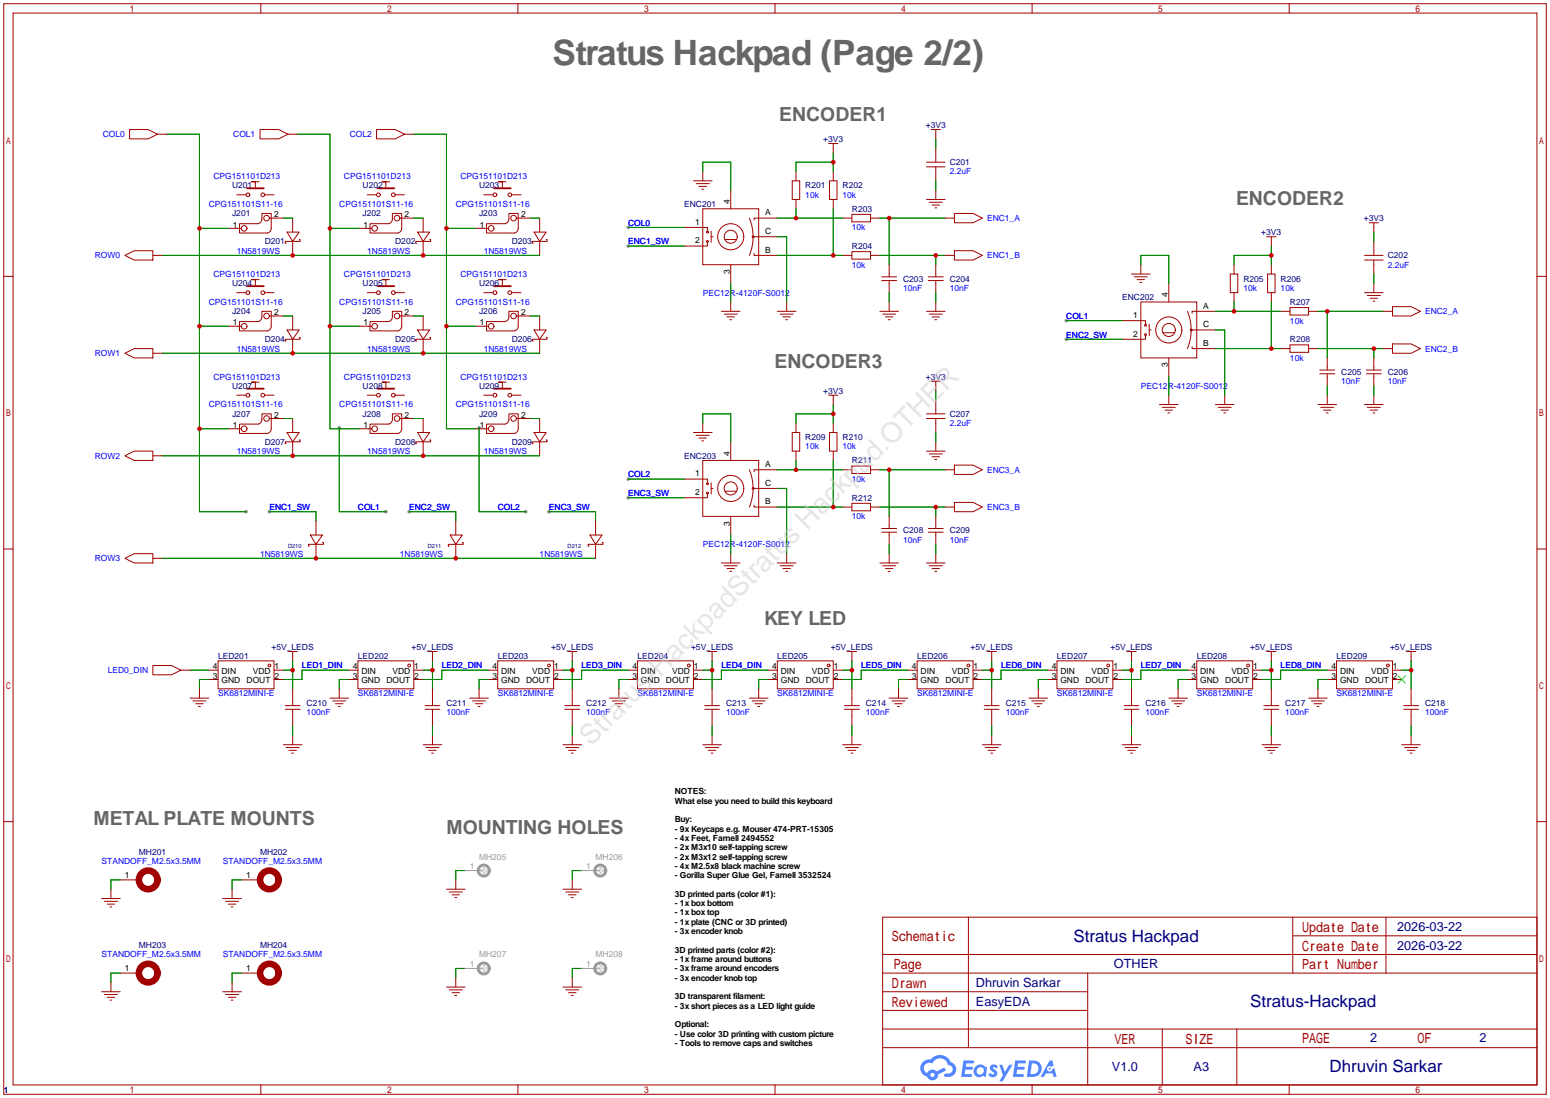
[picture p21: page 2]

NOTES:
What else you need to build this keyboard
Buy:
- 9x Keycaps e.g. Mouser 474-PRT-15305
- 4x Feet, Farnell 2494552
- 2x M3x10 self-tapping screw
- 2x M3x12 self-tapping screw
- 4x M2.5x8 black machine screw
- Gorilla Super Glue Gel, Farnell 3532524
3D printed parts (color #1):
- 1x box bottom
- 1x box top
- 1x plate (CNC or 3D printed)
- 3x encoder knob
3D printed parts (color #2):
- 1x frame around buttons
- 3x frame around encoders
- 3x encoder knob top
3D transparent filament:
- 3x short pieces as a LED light guide
Optional:
- Use color 3D printing with custom picture
- Tools to remove caps and switches

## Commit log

2026-03-23 feat: add 3d models assets and firmware code
    [BOM_Stratus Hackpad_PCB.xlsx, BOM_Stratus Hackpad_PCB_ASM_BOTTOM.xlsx, BOM_Stratus Hackpad_Stratus Hackpad_2026-03-23.csv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]
2026-03-23 Rename Screenshot 2026-03-23 152731.png to PCB!!!!
2026-03-27 Source files
    [1_MCU.schdoc, 2_OTHER.schdoc, BOM.csv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]
